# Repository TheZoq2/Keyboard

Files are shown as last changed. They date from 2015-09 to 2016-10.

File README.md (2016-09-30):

# 60%+ Mechanical Keyboard

This repo contains all the openSCAD and python scripts that I used to create a 3d printed keyboard. 
Other than the components here, you need around 70 cherry style mechanical switches, 70 diodes and 
a teensy or other microcntroller that can act as a USB keyboard. You also need a frame which I 
chose to make out of wood. You can find lots of pictures of the build process and the final result
[here](https://imgur.com/a/YUzv4).

## Generating a layout
If you want a custom layout on your keyboard, you will need to generate it from a layout file exported from 
http://www.keyboard-layout-editor.com/. Click raw data and hit download JSON, save it as layout.json in
the same folder as these scripts.

Next you will need to download my pyScad python script for generating openSCAD models aswell as the
jsonKeyboard.py script in this repository. Run jsonKeyboard and it will print the openSCAD code
for the layout to stdout. Save that code to a file, on unix you can use
```
  python3 jsonKeyboard.py > outputFile.scad
```

Finally, open keyboard.scad in openSCAD and replace the include statement at the top with the filename of 
of your output file, then generate the STL.

## Creating keycaps
At the moment, the keycap scad file is a bit of a mess but there should be some commented code at the bottom
for generating a standard keycap. If you want it rounded, you need to open the exported .stl file in any 
modelling program and round the corners yourself because it's tricky to do in scad. For a standard keycap,
you can use the keycapRounded.stl file in this repo. 

I was able to print all the keycaps facing up and I printed it with a 0.35mm nozzle using a velleman k8400.

##Firmware
In order to use the keyboard you will need some sort of controller that talks to the PC. I decided 
to use a teensy 3.1 which I programmed to act as a keyboard. The code for the firmware that I wrote
can be found [here](https://github.com/TheZoq2/KeyboardFirmware). However, you should be able to use any 
microcontroller you like, assuming it can function as a HID device. 

## Other repos
[PyScad](https://github.com/TheZoq2/py-scad) -- My own script for generating openSCAD models in python.
Required because variables arn't actually variables in scad.  
[KeyboardFirmware](https://github.com/TheZoq2/KeyboardFirmware) -- My code for the teensy microctontroller
inside the keyboard.

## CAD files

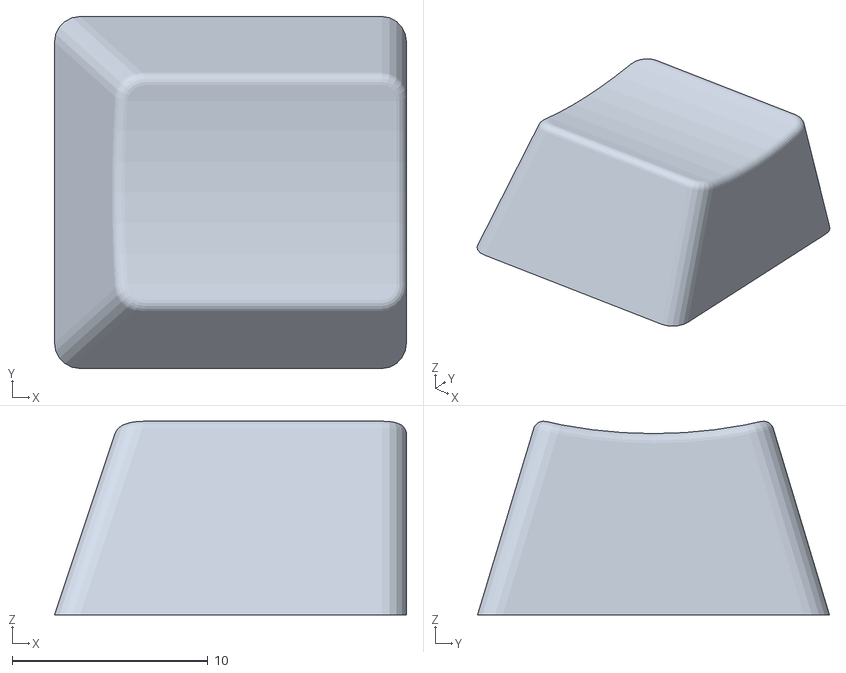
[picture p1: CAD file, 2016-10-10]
keycapRounded.stl
18.0 x 18.0 x 9.90

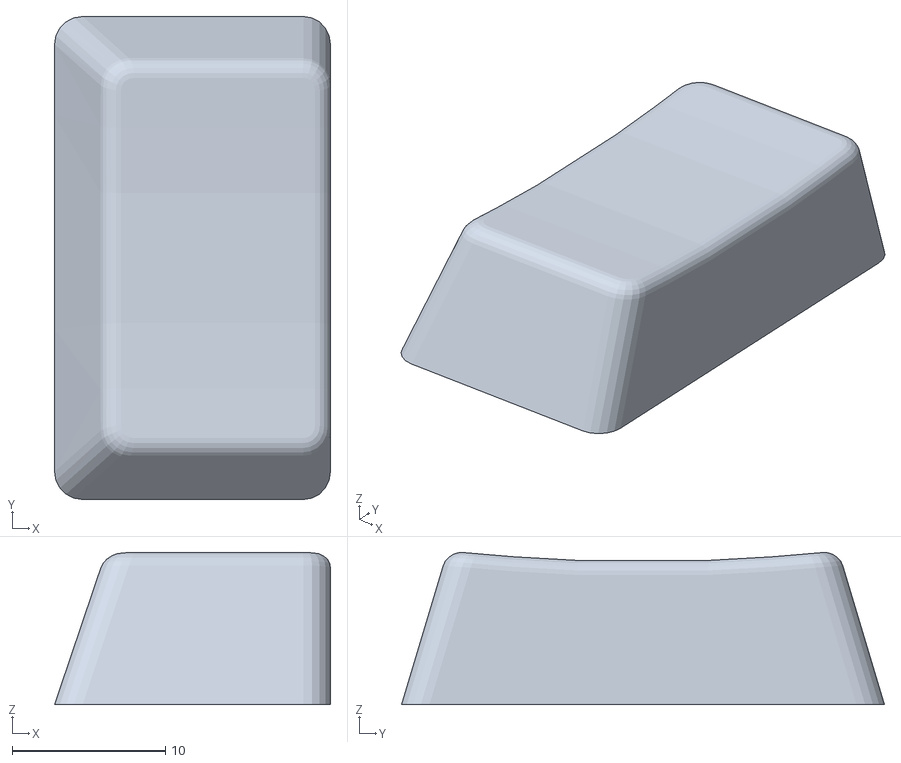
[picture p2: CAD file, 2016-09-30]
stlFiles/keycap_175_rounded.stl
18.0 x 31.5 x 9.92

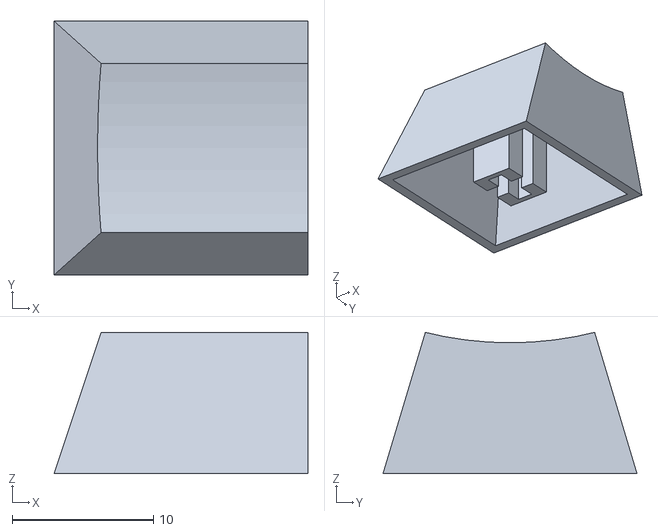
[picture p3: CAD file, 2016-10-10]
keycap.stl
18.0 x 18.0 x 10.0

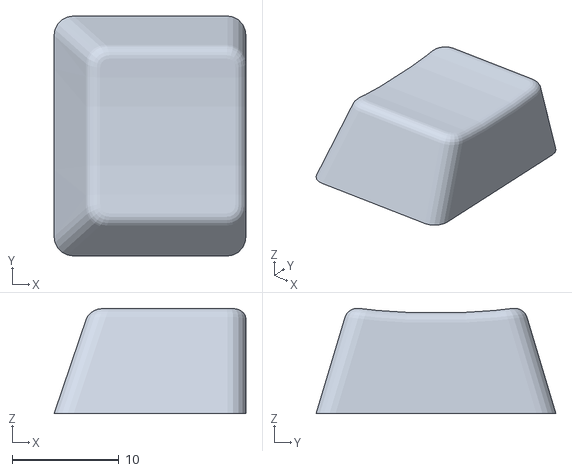
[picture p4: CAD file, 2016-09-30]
stlFiles/keycap_125_rounded.stl
18.0 x 22.5 x 9.88

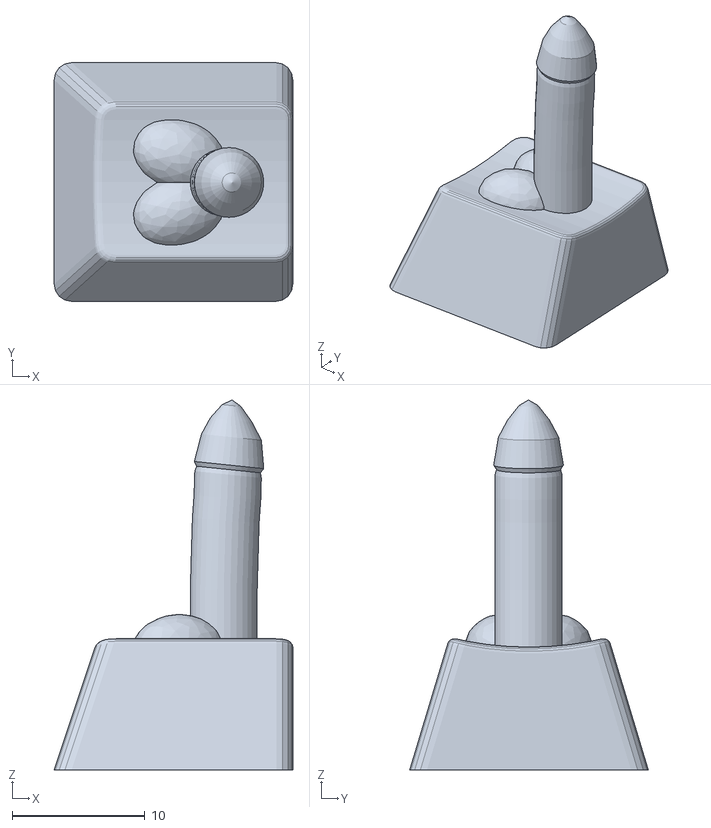
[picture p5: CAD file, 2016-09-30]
keycapDick.stl
18.0 x 18.0 x 27.9

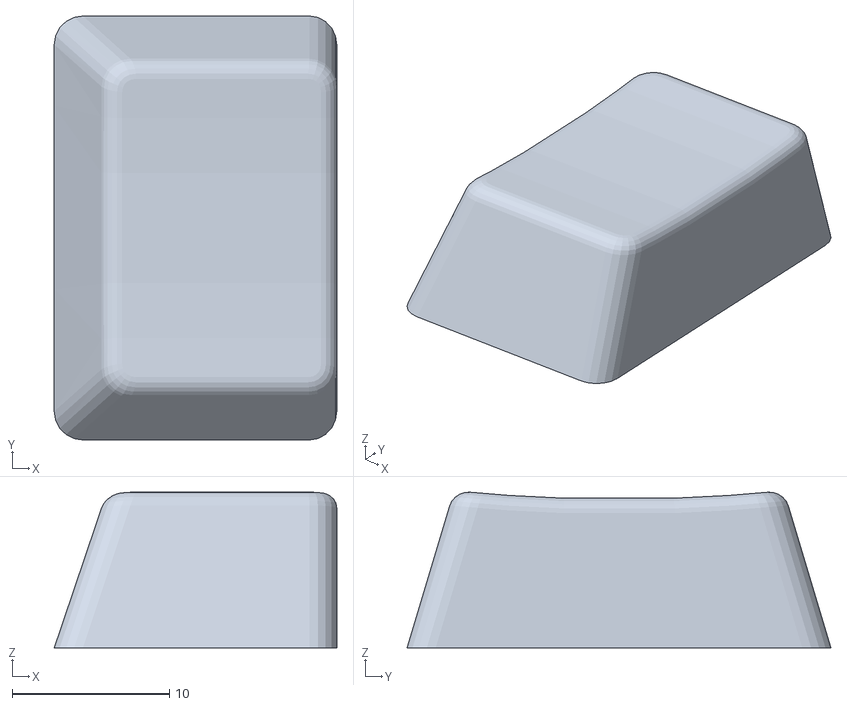
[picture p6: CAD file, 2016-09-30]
stlFiles/keycap_15_rounded.stl
18.0 x 27.0 x 9.92

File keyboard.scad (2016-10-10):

use <ergo.scad>

$fn=30;

module switchHole()
{
    innerHeight = 1.5;
    outerHeight = 100;

    padding = 0.3;
    innerWidth = 14 + padding * 2;
    outerWidth = 16 + padding * 2;
    innerSize = [innerWidth, innerWidth, innerHeight];
    outerSize = [outerWidth, outerWidth, outerHeight];

    
    translate([outerWidth / 2, outerWidth / 2, 0])
    union()
    {
        translate(-[innerWidth / 2, innerWidth / 2, 0])
        cube(innerSize);

        translate([-outerWidth / 2, -outerWidth / 2, innerHeight])
        cube(outerSize);
    }
}

STD_SIZE = 18.5;
FRAME_PADDING = 3;

module part1()
{
    difference()
    {
        //translate([-2, -2, 0])
        //cube([60, 113, 4]);
        translate([-FRAME_PADDING, 0, 0])
        union()
        {
            translate([0,-FRAME_PADDING, 0])
            cube([STD_SIZE * 4 +STD_SIZE*0.25 + FRAME_PADDING, STD_SIZE + FRAME_PADDING, 4]);
            translate([0,STD_SIZE])
            cube([STD_SIZE * 4 + FRAME_PADDING, STD_SIZE, 4]);
            translate([0,STD_SIZE * 2])
            cube([1.5 * STD_SIZE + STD_SIZE * 3 + FRAME_PADDING, STD_SIZE, 4]);
            translate([0,STD_SIZE * 3])
            cube([1.75 * STD_SIZE + STD_SIZE * 3 + FRAME_PADDING, STD_SIZE, 4]);
            translate([0,STD_SIZE * 4])
            cube([1.25 * STD_SIZE + STD_SIZE * 3 + FRAME_PADDING, STD_SIZE, 4]);
            translate([0,STD_SIZE * 5])
            cube([1.25 * STD_SIZE + STD_SIZE * 3 + FRAME_PADDING, STD_SIZE + FRAME_PADDING, 4]);
        }
        switchHoles()
        //cube([14,14,1]);
        switchHole();
    }

    SCREWBLOCK_WIDTH = 6;
    translate([1.75 * STD_SIZE + STD_SIZE * 3 - 2, STD_SIZE * 3.5 - SCREWBLOCK_WIDTH / 2, 1.5])
    {
        difference()
        {
            cube([2,SCREWBLOCK_WIDTH, 6.5+ 4 - 1.5]);
            translate([0,SCREWBLOCK_WIDTH / 2,4 - 1.5 + 4])
            rotate(90, [0,1,0])
            cylinder(d = 3.5, h = 10);
        }
    }
}

module part2()
{
    difference()
    {
        //translate([-2, -2, 0])
        //cube([60, 113, 4]);
        //translate([-FRAME_PADDING, 0, 0])
        union()
        {
            translate([STD_SIZE * 4 +STD_SIZE*0.25,-FRAME_PADDING, 0])
            cube([STD_SIZE * 5 +STD_SIZE*0.25 + FRAME_PADDING, STD_SIZE + FRAME_PADDING, 4]);
            translate([STD_SIZE * 4,STD_SIZE])
            cube([STD_SIZE * 5, STD_SIZE, 4]);
            translate([1.5 * STD_SIZE + STD_SIZE * 3,STD_SIZE * 2])
            cube([STD_SIZE * 5, STD_SIZE, 4]);
            translate([1.75 * STD_SIZE + STD_SIZE * 3,STD_SIZE * 3])
            cube([STD_SIZE * 5, STD_SIZE, 4]);
            translate([1.25 * STD_SIZE + STD_SIZE * 3,STD_SIZE * 4])
            cube([STD_SIZE * 5, STD_SIZE, 4]);
            translate([1.25 * STD_SIZE + STD_SIZE * 3,STD_SIZE * 5])
            cube([STD_SIZE * 5, STD_SIZE + FRAME_PADDING, 4]);
        }
        switchHoles()
        //cube([14,14,1]);
        switchHole();
    }

    SCREWBLOCK_WIDTH = 6;
    translate([1.75 * STD_SIZE + STD_SIZE * 3, STD_SIZE * 3.5 - SCREWBLOCK_WIDTH / 2, 1.5])
    {
        difference()
        {
            cube([2,SCREWBLOCK_WIDTH, 6.5+ 4 - 1.5]);
            translate([0,SCREWBLOCK_WIDTH / 2,4 - 1.5 + 4])
            rotate(90, [0,1,0])
            cylinder(d = 3.5, h = 10);
        }
    }
    SCREWBLOCK_WIDTH = 6;
    translate([1.75 * STD_SIZE + STD_SIZE * 8 - 2, STD_SIZE * 3.5 - SCREWBLOCK_WIDTH / 2, 1.5])
    {
        difference()
        {
            cube([2,SCREWBLOCK_WIDTH, 6.5+ 4 - 1.5]);
            translate([0,SCREWBLOCK_WIDTH / 2,4 - 1.5 + 4])
            rotate(90, [0,1,0])
            cylinder(d = 3.5, h = 10);
        }
    }
}
module part3()
{
    difference()
    {
        //translate([-2, -2, 0])
        //cube([60, 113, 4]);
        //translate([-FRAME_PADDING, 0, 0])
        union()
        {
            translate([STD_SIZE * 9 + STD_SIZE * 0.66,-FRAME_PADDING, 0])
            cube([STD_SIZE * 5 + STD_SIZE*0.5 , STD_SIZE + FRAME_PADDING, 4]);

            translate([STD_SIZE * 9,STD_SIZE, 0])
            cube([STD_SIZE * 4 + STD_SIZE * 2 + FRAME_PADDING, STD_SIZE, 4]);

            translate([1.5 * STD_SIZE + STD_SIZE * 8,STD_SIZE * 2])
            cube([STD_SIZE * 4 + STD_SIZE * 1.5 + FRAME_PADDING, STD_SIZE, 4]);

            translate([1.75 * STD_SIZE + STD_SIZE * 8,STD_SIZE * 3])
            cube([STD_SIZE * 3 + STD_SIZE * 2.25 + FRAME_PADDING, STD_SIZE, 4]);

            translate([1.25 * STD_SIZE + STD_SIZE * 8,STD_SIZE * 4])
            cube([STD_SIZE * 4 + STD_SIZE * 1.75 + FRAME_PADDING, STD_SIZE, 4]);

            translate([1.25 * STD_SIZE + STD_SIZE * 8,STD_SIZE * 5])
            cube([STD_SIZE * 4 + STD_SIZE * 1.75 + FRAME_PADDING, STD_SIZE + FRAME_PADDING, 4]);
        }
        switchHoles()
        //cube([14,14,1]);
        switchHole();
    }

    SCREWBLOCK_WIDTH = 6;
    translate([1.75 * STD_SIZE + STD_SIZE * 8, STD_SIZE * 3.5 - SCREWBLOCK_WIDTH / 2, 1.5])
    {
        difference()
        {
            cube([2,SCREWBLOCK_WIDTH, 6.5+ 4 - 1.5]);
            translate([0,SCREWBLOCK_WIDTH / 2,4 - 1.5 + 4])
            rotate(90, [0,1,0])
            cylinder(d = 3.5, h = 10);
        }
    }
}

//part1();
//part2();
//part3();

HEIGHT = 4;

difference()
{
    cube([130,130, HEIGHT]);
    switchHoles()
    switchHole();
}

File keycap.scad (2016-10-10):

$fn = 100;

module mountingCross(width, length, barWidth, height, useSupport = false)
{
    diameter = 6;
    barLength = 4.7;
    
    rotate(90)
    difference()
    {
        //cylinder(d = diameter, h = height);
        union()
        {
            //cylinder(d = diameter, h = height);
            translate(- [width / 2, length / 2, 0])
            cube([width, length, height], centered=true);

            if(useSupport)
            {
                translate([0,-50,0])
                cube([0.5, 100, 2 * height / 3]);
            }
        }

        translate([-barWidth / 2, -barLength / 2, 0])
        cube([barWidth, barLength, height]);
        
        
        rotate(90)
        {
            translate([-barWidth / 2, -barLength, 0])
            cube([barWidth, barLength * 2, height]);
        }
    }
}
module stabilizerMounts(size, holeSize, interDistance, startHeight)
{
    for(i = [-1, 1])
    {
        translate([-size[0] / 2, interDistance * i - size[1] / 2, startHeight])
        difference()
        {
            cube(size);
            translate([size[0] / 2 - holeSize[0] / 2, size[1] / 2 - holeSize[1] / 2, 0])
            cube([holeSize[0], holeSize[1], size[2]]);
            //rotate(90)
            //children(0);
        }
    }
}

module keycapShape(width, length, height, topWidth, topLength, roundTop = true)
{
    //Parameters
    //width = 18;
    //length = 18;
    //height = 12;
    roundoffRadius = 25;

    //Calculating the angles of the "cutters"

    sideDifference = (width - topWidth) / 2;
    sideCutAngle = atan(height / sideDifference);
    frontDifference = (length - topLength);
    frontCutAngle = atan(length / frontDifference);
    
    roundoffHeight = sqrt(pow(roundoffRadius, 2) - pow(topLength / 2, 2));

    difference()
    {
        cube([width, length, height]);

        translate([-1,0,0])
        for(i = [0 , 1])
        {
            translate([0,i * length,0])
            mirror([0,i,0])
            rotate(sideCutAngle, [1,0,0])
            cube([width * 2, length * 2, height * 2]);
        }
        
        //Cutting of the front face
        translate([-1,0,0]);
        rotate(-frontCutAngle, [0,1,0])
        cube([width * 2, length * 2, height * 2]);

        if(roundTop)
        {
            //Rounding off the top
            translate([0, length / 2, height + roundoffHeight])
            rotate(90, [0,1,0])
            cylinder(r = roundoffRadius, h = length * 2);
        }
    }
    
}

module supportV(width, length, height)
{
    cubeWidth = sqrt(pow(width / 2, 2) + pow(height, 2));
    angle = atan(height / (width / 2));

    translate([0, -length / 2, -height])
    for(i = [0,1])
    {
        mirror([i,0,0])
        rotate(-angle, [0,1,0])
        cube([cubeWidth, length, height]);
    }
}

module supportTriangle(width, length, height)
{
    intersection()
    {
        supportV(width, length, height);
        rotate(90)
        supportV(width, length, height);
    }
}

module keycap(outerSize, topSize, roundTop = true, useSupport = true)
{
    width = outerSize[0];
    length = outerSize[1];
    //height = 12;
    height = 10;
    topWidth = topSize[0];
    topLength = topSize[1];

    thickness = 1;
    supportHeight = 4;

    crossStartHeight = 0;

    intersection()
    {
        keycapShape(width, length, height, topWidth, topLength, roundTop = roundTop);
        union()
        {
            difference()
            {
                keycapShape(width, length, height, topWidth, topLength, roundTop = roundTop);
                translate([thickness, thickness, 0])
                keycapShape(width - thickness * 2, length - thickness * 2, height - thickness * 2, topWidth - thickness * 2, topLength - thickness * 2, roundTop = roundTop);
            }

            if(useSupport)
            {
                //Support structure
                translate([width - topWidth / 2 - thickness, length / 2, height - thickness * 2])
                supportTriangle(topWidth, topLength, supportHeight);
            }

            //translate([width / 2 - 2, length / 2 - 2, 0])
            //cube([4, 4, height]);
            translate([width / 2, length / 2, crossStartHeight])
            {
                rotate(90)
                children(0);
            }

            
            translate([width/2 -2.5, length / 2-2.5,0])
            difference()
            {
                cube([5,5,crossStartHeight]);
                translate([1,0,0])
                cube([3,6,crossStartHeight]);
            }
        }
    }
}


crossWidth = 1.5;

STD_OUTER_SIZE = [18, 18];
STD_INNER_SIZE = [12, 12];

STD_OUTER_SIZE = [18, 18];
STD_INNER_SIZE = [12, 12];

R_SHIFT_OUTER = [STD_OUTER_SIZE[0], STD_OUTER_SIZE[1]];
R_SHIFT_INNER = [STD_INNER_SIZE[0], STD_INNER_SIZE[1]];

MOUNT_OUTER_SIZE = [4.3, 5.8, 8]; //Does not affect the keycaps for now
MOUNT_CAP_SIZE = [4.3, 5.8, 3];

ST_MOUNT_OUTERSIZE = [10,5,100];
ST_MOUNT_HOLE_SIZE = [7,1];
ST_INTER_DISTANCE = 14;
ST_START_HEIGHT = 3;

keycap(STD_OUTER_SIZE, STD_INNER_SIZE, roundTop = true, useSupport = false)
mountingCross(MOUNT_OUTER_SIZE[0], MOUNT_OUTER_SIZE[1], 1.6, MOUNT_OUTER_SIZE[2], useSupport = false)
cube([0,0,0]);

//keycap(R_SHIFT_OUTER, R_SHIFT_INNER, roundTop = false, useSupport = true)
//union()
//{
//    rotate(90)
//    mountingCross(4, 5.5, crossWidth, 10, useSupport = false)
//    stabilizerMounts(ST_MOUNT_OUTERSIZE, ST_MOUNT_HOLE_SIZE, ST_INTER_DISTANCE, ST_START_HEIGHT);
//    //mountingCross(4, 5.5, crossWidth, 10, useSupport = false);
//}


//mountingCross(MOUNT_OUTER_SIZE[0], MOUNT_OUTER_SIZE[1], 1.6, MOUNT_OUTER_SIZE[2], useSupport = false);
//rotate(-90)
//translate([-MOUNT_CAP_SIZE[0] / 2, -MOUNT_CAP_SIZE[1] / 2, MOUNT_OUTER_SIZE[2] - MOUNT_CAP_SIZE[2]])
//{
//    cube(MOUNT_CAP_SIZE);
//}

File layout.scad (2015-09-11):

module switchHoles()
{
translate([9.25,9.25,0])
{
children(0);
}
translate([32.375,9.25,0])
{
children(0);
}
translate([50.875,9.25,0])
{
children(0);
}
translate([69.375,9.25,0])
{
children(0);
}
translate([87.875,9.25,0])
{
children(0);
}
translate([111.0,9.25,0])
{
children(0);
}
translate([129.5,9.25,0])
{
children(0);
}
translate([148.0,9.25,0])
{
children(0);
}
translate([166.5,9.25,0])
{
children(0);
}
translate([189.625,9.25,0])
{
children(0);
}
translate([208.125,9.25,0])
{
children(0);
}
translate([226.625,9.25,0])
{
children(0);
}
translate([245.125,9.25,0])
{
children(0);
}
translate([268.25,9.25,0])
{
children(0);
}
translate([9.25,27.75,0])
{
children(0);
}
translate([27.75,27.75,0])
{
children(0);
}
translate([46.25,27.75,0])
{
children(0);
}
translate([64.75,27.75,0])
{
children(0);
}
translate([83.25,27.75,0])
{
children(0);
}
translate([101.75,27.75,0])
{
children(0);
}
translate([120.25,27.75,0])
{
children(0);
}
translate([138.75,27.75,0])
{
children(0);
}
translate([157.25,27.75,0])
{
children(0);
}
translate([175.75,27.75,0])
{
children(0);
}
translate([194.25,27.75,0])
{
children(0);
}
translate([212.75,27.75,0])
{
children(0);
}
translate([231.25,27.75,0])
{
children(0);
}
translate([259.0,27.75,0])
{
children(0);
}
translate([13.875,46.25,0])
{
children(0);
}
translate([37.0,46.25,0])
{
children(0);
}
translate([55.5,46.25,0])
{
children(0);
}
translate([74.0,46.25,0])
{
children(0);
}
translate([92.5,46.25,0])
{
children(0);
}
translate([111.0,46.25,0])
{
children(0);
}
translate([129.5,46.25,0])
{
children(0);
}
translate([148.0,46.25,0])
{
children(0);
}
translate([166.5,46.25,0])
{
children(0);
}
translate([185.0,46.25,0])
{
children(0);
}
translate([203.5,46.25,0])
{
children(0);
}
translate([222.0,46.25,0])
{
children(0);
}
translate([240.5,46.25,0])
{
children(0);
}
translate([263.625,46.25,0])
{
children(0);
}
translate([16.1875,64.75,0])
{
children(0);
}
translate([41.625,64.75,0])
{
children(0);
}
translate([60.125,64.75,0])
{
children(0);
}
translate([78.625,64.75,0])
{
children(0);
}
translate([97.125,64.75,0])
{
children(0);
}
translate([115.625,64.75,0])
{
children(0);
}
translate([134.125,64.75,0])
{
children(0);
}
translate([152.625,64.75,0])
{
children(0);
}
translate([171.125,64.75,0])
{
children(0);
}
translate([189.625,64.75,0])
{
children(0);
}
translate([208.125,64.75,0])
{
children(0);
}
translate([226.625,64.75,0])
{
children(0);
}
translate([256.6875,64.75,0])
{
children(0);
}
translate([11.5625,83.25,0])
{
children(0);
}
translate([32.375,83.25,0])
{
children(0);
}
translate([50.875,83.25,0])
{
children(0);
}
translate([69.375,83.25,0])
{
children(0);
}
translate([87.875,83.25,0])
{
children(0);
}
translate([106.375,83.25,0])
{
children(0);
}
translate([124.875,83.25,0])
{
children(0);
}
translate([143.375,83.25,0])
{
children(0);
}
translate([161.875,83.25,0])
{
children(0);
}
translate([180.375,83.25,0])
{
children(0);
}
translate([198.875,83.25,0])
{
children(0);
}
translate([217.375,83.25,0])
{
children(0);
}
translate([242.8125,83.25,0])
{
children(0);
}
translate([268.25,83.25,0])
{
children(0);
}
translate([11.5625,101.75,0])
{
children(0);
}
translate([32.375,101.75,0])
{
children(0);
}
translate([50.875,101.75,0])
{
children(0);
}
translate([69.375,101.75,0])
{
children(0);
}
translate([131.8125,101.75,0])
{
children(0);
}
translate([194.25,101.75,0])
{
children(0);
}
translate([212.75,101.75,0])
{
children(0);
}
translate([231.25,101.75,0])
{
children(0);
}
translate([249.75,101.75,0])
{
children(0);
}
translate([268.25,101.75,0])
{
children(0);
}
}

switchHoles()
cube([14,14,1]);

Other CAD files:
plate.scad
keycapRounded.blend
plateTest.scad
stabilizer.scad
stlFiles/keycapRounded.stl

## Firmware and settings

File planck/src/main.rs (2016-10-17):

//"Import" the module along with the macros
#[macro_use]
extern crate scad_generator;
extern crate scad_util as su;

//Avoid having to write scad_generator:: everywhere
use scad_generator::*;
use su::electronics;

enum Side
{
    LEFT,
    RIGHT
}

fn get_usb_port_mount() -> ScadObject
{
    let breakout = electronics::PolouMicroUsbBreakout::new();

    let triangle_width = breakout.width;
    let triangle_length = breakout.hole_diameter + breakout.hole_distance_from_back;

    let triangle = {
        let cube = scad!(Cube(vec3(triangle_width, triangle_length, triangle_length)));

        let cutout = scad!(Rotate(45., vec3(1., 0., 0.));
        {
            scad!(Cube(vec3(triangle_width, triangle_length * 2., triangle_length * 2.))),
        });

        scad!(Translate(vec3(0.,triangle_length,0.));{
            scad!(Rotate(180., vec3(1., 0., 0.));
            {
                scad!(Difference;
                {
                    cube,
                    cutout
                })
            })
        })
    };


    scad!(Union;
    {
        scad!(Translate(vec3(-triangle_width / 2., 0., 0.));{
            triangle
        }),
        breakout.hole_shape()
    })
}

//1.5mm chamfer is added after generation in blender.
qstruct!(Keyboard(rows: i32, cols: i32)
{
    rows: i32 = rows,
    cols: i32 = cols,
    grid_spacing: f32 = 18.5,
    top_thickness: f32 = 1.5,
    side_thickness: f32 = 3.0,
    inner_height: f32 = 12.,
});


impl Keyboard 
{
    pub fn get_main(&self, side: Side) -> ScadObject
    {
        let grid = 
        {
            let height_offset =  self.total_height() - self.top_thickness;
            scad!(Translate(vec3(0., 0., height_offset));
            {
                self.get_grid(),
                self.get_screwholes()
            })
        };

        let (usb_port_hole, usb_port_mount) = match side
        {
            Side::LEFT =>
            {
                let tuples = vec!(self.usb_mount(Side::LEFT), self.usb_mount(Side::RIGHT));

                let mut holes = scad!(Union);
                let mut mounts = scad!(Union);

                for (hole, mount) in tuples
                {
                    holes.add_child(hole);
                    mounts.add_child(mount);
                }

                (holes, mounts)
            }
            Side::RIGHT =>
            {
                self.usb_mount(Side::RIGHT)
            }
        };

        scad!(Difference;{
            scad!(Union;
            {
                self.get_frame(),
                usb_port_mount
            }),
            grid,
            usb_port_hole,
            self.get_magnets(side)
        })
    }

    fn usb_mount(&self, position: Side) -> (ScadObject, ScadObject)
    {
        let bottom_offset = 2.;
        let usb_breakout = electronics::PolouMicroUsbBreakout::new();

        let usb_offset_x = match position
        {
            Side::RIGHT => self.rows as f32 - 1.,
            Side::LEFT => 1.
        };
        let usb_offset_y = 0.;

        let usb_port_hole = {
            scad!(Translate(vec3(self.grid_spacing * usb_offset_x, -usb_offset_y, bottom_offset)); usb_breakout.board(10.))
        };
        let usb_port_mount = {
            let mount = scad!(Translate(vec3(self.grid_spacing * usb_offset_x, -usb_offset_y, -bottom_offset));
                {
                    get_usb_port_mount()
                });

            let flipped = scad!(Mirror(vec3(0.,0.,1.));mount);

            scad!(Translate(vec3(0., 0., usb_breakout.height));flipped)
        };
        
        (usb_port_hole, usb_port_mount)
    }

    pub fn get_frame(&self) -> ScadObject 
    {
        let inner_length = self.grid_spacing * self.rows as f32;
        let inner_width = self.grid_spacing * self.cols as f32;
        let length = inner_length + self.side_thickness * 2.;
        let width = inner_width+ self.side_thickness * 2.;
        let thickness = self.total_height();

        let main_cube = 
        {
            let cube = scad!(Cube(vec3(length, width, thickness)));
            
            scad!(Translate(vec3(-self.side_thickness, -self.side_thickness, 0.));{cube})
        };


        let inner_height = self.total_height() - self.top_thickness;
        let cutout = scad!(Cube(vec3(inner_length, inner_width, inner_height)));
        
        scad!(Difference;{
            main_cube,
            cutout
        })
    }


    pub fn get_grid(&self) -> ScadObject
    {
        let mut result  = scad!(Union);

        for x in 0..self.rows
        {
            for y in 0..self.cols
            {
                let x_pos = x as f32 * self.grid_spacing + self.grid_spacing / 2.;
                let y_pos = y as f32 * self.grid_spacing + self.grid_spacing / 2.;

                //let cube = scad!(Cube(vec3(15.0, 15.0, 5.0)));
                let translated = scad!(
                    Translate(vec3(x_pos, y_pos, 0.0));{
                        get_switch_hole()
                    });

                result.add_child(translated);
            }
        }
        
        result
    }


    pub fn get_screwholes(&self) -> ScadObject 
    {
        let x_positions = vec!(1, self.rows / 2, self.rows - 1);
        let y_positions = vec!(1, self.cols - 1);

        let screwhole_radius = 3.0;

        let mut result = scad!(Union);

        let screwhole = scad!(Cylinder(self.top_thickness, Diameter(screwhole_radius)));

        for x in x_positions.clone()
        {
            for y in y_positions.clone()
            {
                let x_pos = x as f32 * self.grid_spacing;
                let y_pos = y as f32 * self.grid_spacing;

                let translated = scad!(Translate(vec3(x_pos, y_pos, 0.));
                {
                    screwhole.clone()
                });

                result.add_child(translated);
            }
        }
        return result;
    }

    fn total_height(&self) -> f32
    {
        self.top_thickness + self.inner_height
    }

    fn get_magnets(&self, side: Side) -> ScadObject
    {
        let diameter = 5.8;
        let height = 2.2;
        let bottom_offset = diameter;
        
        let magnet = 
        {
            let cylinder = scad!(Cylinder(height, Diameter(diameter)));

            let rotated = scad!(Rotate(90., vec3(0., 1., 0.)); cylinder);

            scad!(Translate(vec3(0., 0., bottom_offset)); rotated)
        };

        let duplicated = 
        {
            let first = scad!(Translate(vec3(0., self.grid_spacing / 2., 0.)); magnet.clone());
            let second = scad!(Translate(vec3(0., self.grid_spacing * (self.cols as f32 - 0.5), 0.)); magnet.clone());

            scad!(Union;
            {
                first,
                second
            })
        };


        match side
        {
            Side::RIGHT => {
                scad!(Translate(vec3(self.rows as f32 * self.grid_spacing, 0., 0.)); duplicated)
            },
            Side::LEFT => {
                scad!(Translate(vec3(-height, 0., 0.)); duplicated)
            }
        }

    }
}


fn get_switch_hole() -> ScadObject 
{
    let inner_height = 1.5;
    let padding = 0.2;
    let inner_width = 14. + padding * 2.;

    let cube = scad!(Cube(vec3(inner_width, inner_width, inner_height)));

    scad!(Translate(vec3(-inner_width / 2., -inner_width / 2., 0.));
    {
        cube
    })
}


pub fn main()
{
    //Create an scad file object for storing the scad objects. This
    //allows us to set things like the detail level ($fn) for the models.
    let mut sfile = ScadFile::new();

    //Sets the $fn variable in scad which controls the detail level of things
    //like spheres. Look at the scad wiki for details
    sfile.set_detail(50);

    //Add the cube object to the file
    sfile.add_object(Keyboard::new(6, 4).get_main(Side::LEFT));
    //sfile.add_object(Keyboard::new(3, 3).get_main(Side::LEFT));
    //sfile.add_object(get_usb_port_mount());
    //sfile.add_object(electronics.teensy_lc());
    //Save the scad code to a file
    sfile.write_to_file(String::from("out.scad"));
}

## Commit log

2015-09-08 Added a bunch of scad files
    [keycap.scad, plate.scad, plateTest.scad]
2015-09-08 Made cherry cross work well when printed
    [keycap.scad]
2015-09-09 updated keyboard layout
    [keyboard.scad, layout.scad]
2015-09-10 added stabilizers for keys
    [keyboard.scad, keycap.scad, layout.scad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]
2015-09-11 added JSON reading to read keyboard layout from keyboard-layout-editor.com
    [layout.scad]
2015-09-11 Experimented with stabilizers
    [keycap.scad, plateTest.scad, stabilizer.scad]
2015-10-09 Added keycap.stl
    [keycap.stl]
2015-10-09 added keycap stl and blend files
    [keycapRounded.blend, keycapRounded.stl]
2016-03-04 Add dick
    [keycapDick.stl]
2016-03-04 Add stl versions of all the rounded files
    [keyboard.scad, keycap.scad, keycapRounded.stl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]
2016-10-10 Add magnets and a teensy
    [keyboard.scad, keycap.scad, keycap.stl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]
